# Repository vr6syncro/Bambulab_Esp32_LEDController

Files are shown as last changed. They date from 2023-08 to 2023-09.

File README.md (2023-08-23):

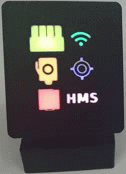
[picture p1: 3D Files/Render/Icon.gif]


# Bambulab Esp32 LEDController #

## Quick getting started - [for more details check this WIKI!](https://github.com/vr6syncro/Bambulab_Esp32_LEDController/wiki)

[Click here to get to the flasher.](https://vr6syncro.de/programmer/esp32.html "Click here to get to the flasher.")

The ESP32 is flashed with the firmware.

The ESP32 is now building a W-Lan access point with which we connect. The current password is: `password`

After that we have to navigate to the Wifimanager Config page with a browser.
The IP is: `192.168.4.1`

There you enter your W-Lan registration data.

Optionally, the Bambulab printer can be set up now or you can set it up later via the serial console or via the website.

If the EPS32 is connected to the WiFi, you should be able to find and reach it in your network.
The IP of the device is also output via the console if a programming app is installed.

As soon as you enter the IP of the EPS32 in your browser, you will get to the welcome page.
On the right side of the navigation you get to the configuration.

If the printer is not already connected, it reboots once after saving the data and it should connect to the MQTT.

[The 3D Files are at Printables, click here!](https://www.printables.com/de/model/501355-bambulab-esp32-ledcontroller)

## Hardware Infos
For a list of working ESP32 Controllers see [release](https://github.com/vr6syncro/Bambulab_Esp32_LEDController/releases).
    
    Pin 16 is connected with WS2812B Data Pin.

## OBS Stream Overlay
Just add your device ip/obs as webpage to OBS. If you want to change something you need to edit the obs file in src directory and self compile.

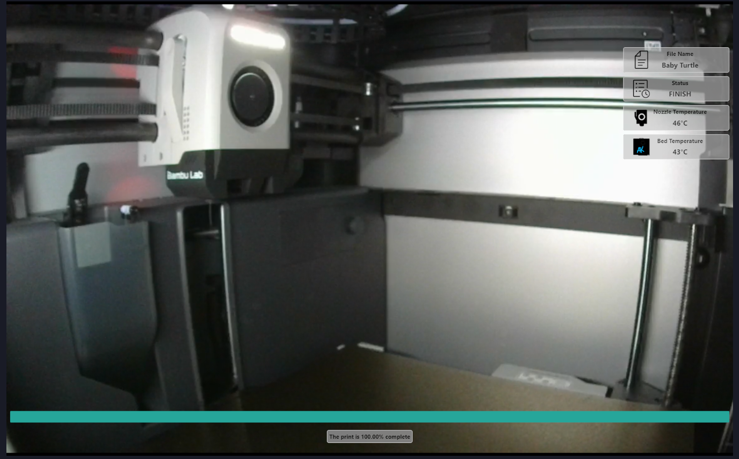
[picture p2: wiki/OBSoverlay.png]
overlay


### For more infos and help see my discord at: [http://discord.vr6syncro.de](http://discord.vr6syncro.de)

<a href="https://www.buymeacoffee.com/vr6syncro" target="_blank">Buy Me A Drink</a>

## License
This project is licensed under the "Attribution-NonCommercial-ShareAlike 4.0 International" License. See the [LICENSE](LICENSE) file for more details.

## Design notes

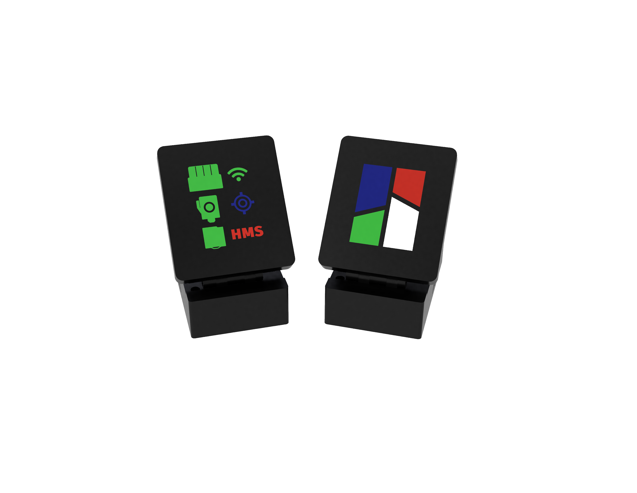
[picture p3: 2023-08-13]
3D Files/Render/Front.PNG

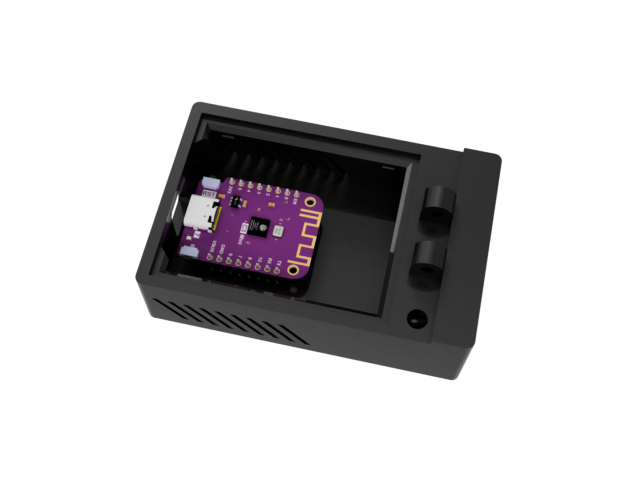
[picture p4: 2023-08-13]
3D Files/Render/Wemos C3.png

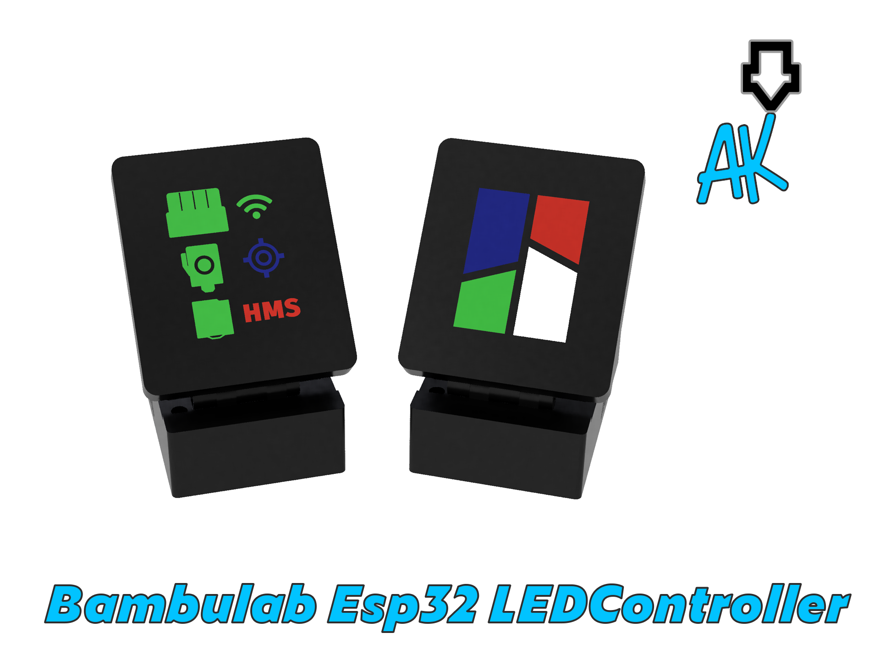
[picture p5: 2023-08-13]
3D Files/Render/Titelbild.png

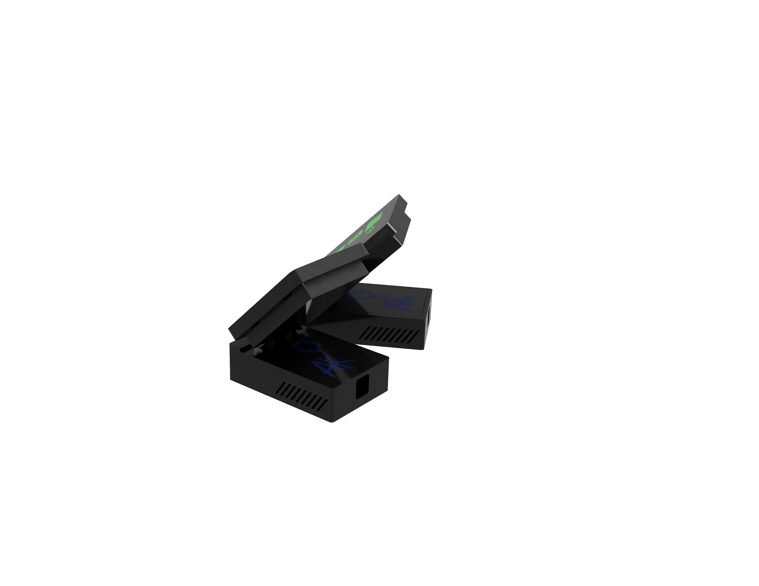
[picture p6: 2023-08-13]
3D Files/Render/Side.png

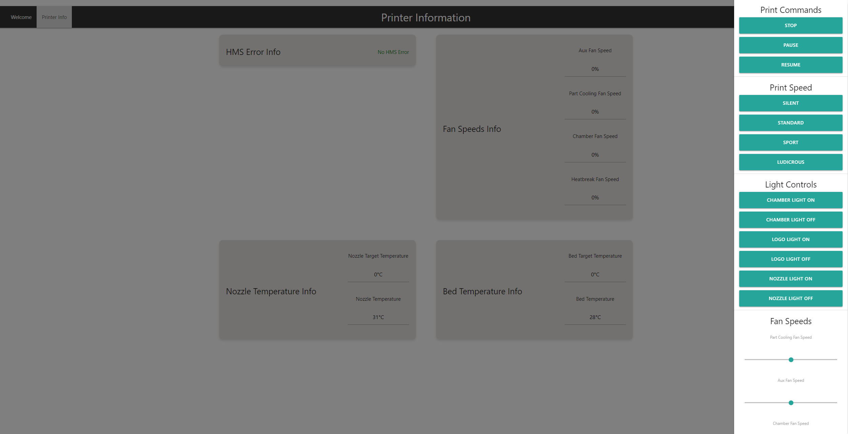
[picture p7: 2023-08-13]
wiki/CommandSidebar.png

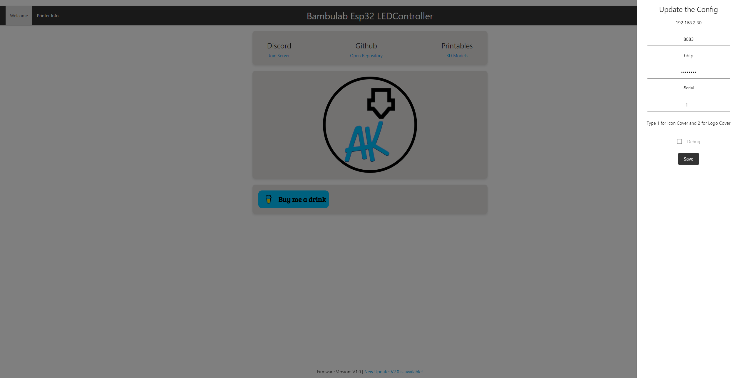
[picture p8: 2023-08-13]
wiki/ConfigSidebar.png

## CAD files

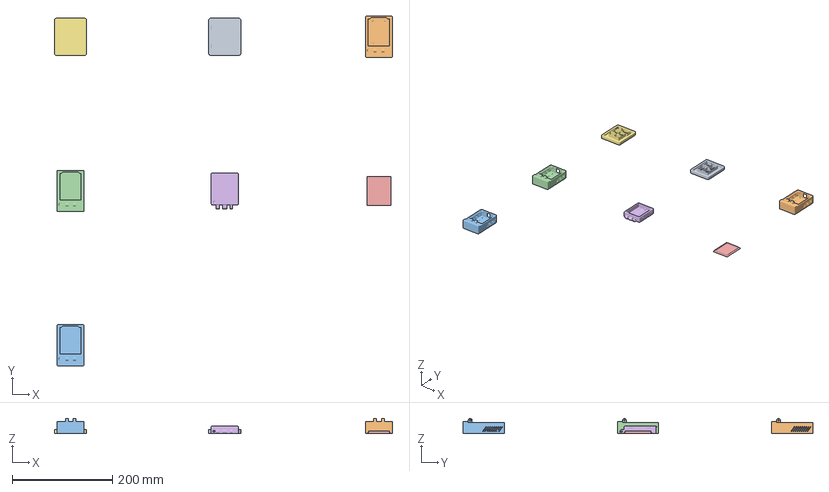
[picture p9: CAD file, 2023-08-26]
3D Files/Project File.3mf
673.4 x 696.7 x 30.0 mm
Frontcover Bambu Logo
Gehäuse_Dev Board and NodeMCU_V2
Gehäuse_Esp32_Wemos_d1_mini_V2
Gehäuse_ESP32_Wemos_C3_S2_V2
Deckel
Unterteil
Frontcover Icon

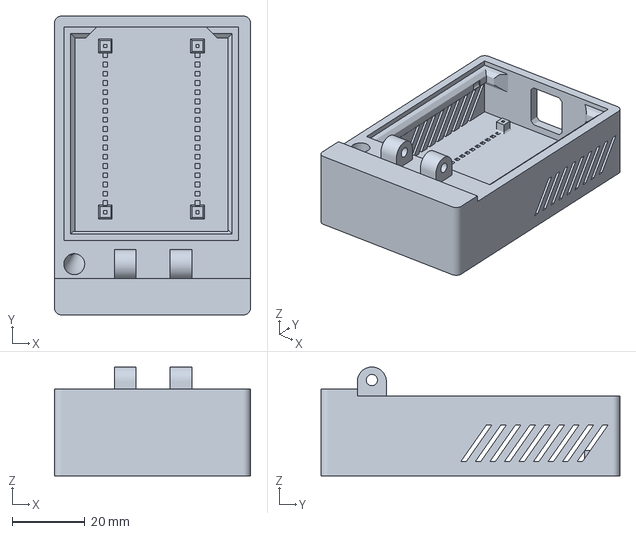
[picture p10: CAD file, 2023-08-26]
3D Files/Gehäuse_Dev Board and NodeMCU_V2.3mf
54.0 x 82.3 x 30.0 mm

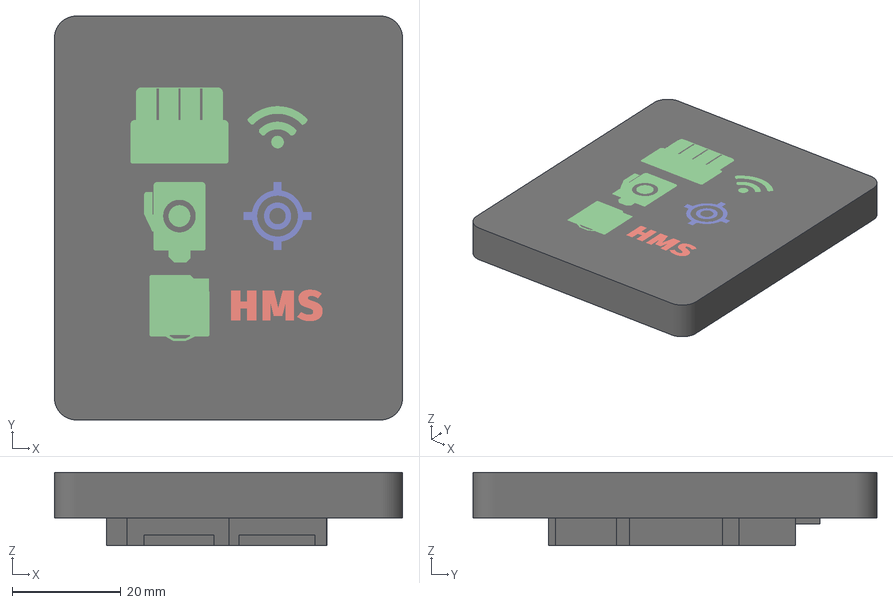
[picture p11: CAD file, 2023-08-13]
3D Files/Frontcover Icon.3mf
64.0 x 74.3 x 13.5 mm

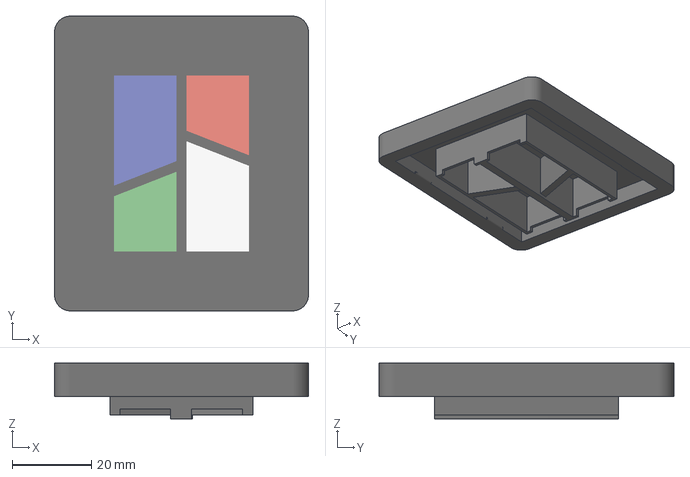
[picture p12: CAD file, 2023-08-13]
3D Files/Frontcover Bambu Logo.3mf
64.0 x 74.3 x 14.0 mm

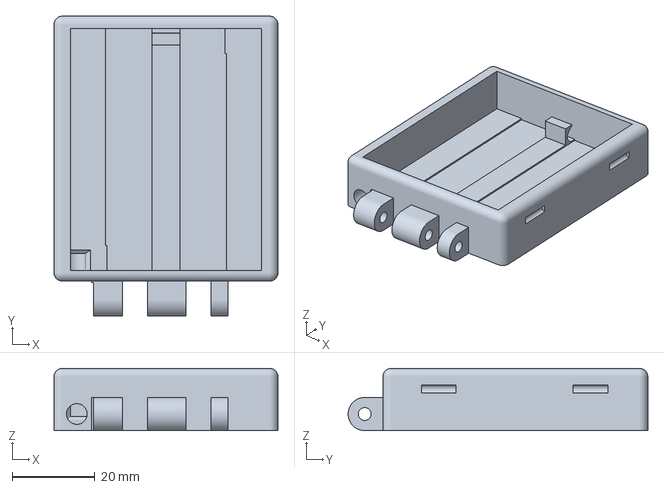
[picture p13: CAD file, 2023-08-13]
3D Files/Unterteil.3mf
54.0 x 72.3 x 15.0 mm

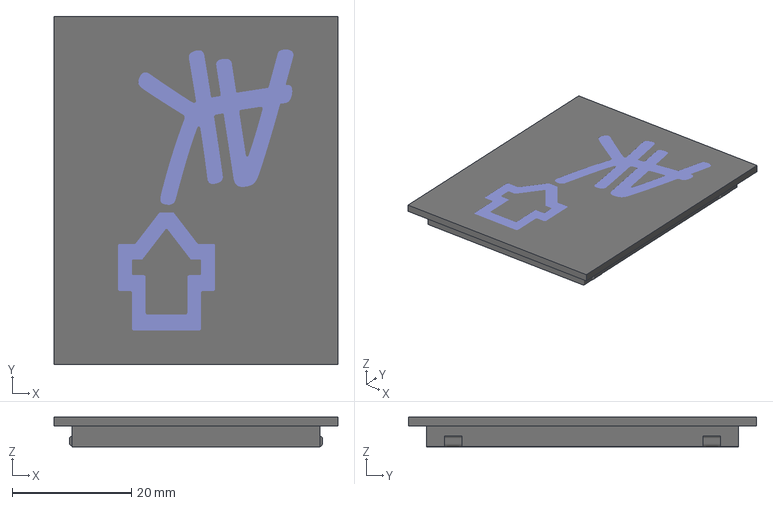
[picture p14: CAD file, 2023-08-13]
3D Files/Deckel.3mf
47.6 x 58.4 x 5.00 mm

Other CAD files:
3D Files/Gehäuse_Esp32_Wemos_d1_mini_V2.3mf
3D Files/Gehäuse_ESP32_Wemos_C3_S2_V2.3mf

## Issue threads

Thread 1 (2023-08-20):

NodeMCU V3.4 kompatibel?

PrintModz, 2023-08-20:
Ich versuche gerade die .bin Datei für das oben genannte Board aufzuspielen, jedoch ohne Erfolg. Der Flasher sagt andauernd, dass es sich um keine ESP Board handelt, obwohl es jedoch unter Arduino funktioniert.

Gibt es da vielleicht einen Trick?

Closed 2023-08-20.

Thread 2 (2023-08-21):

Your ESP8266 board is not supported.

PrintModz, 2023-08-21:
Hey,
die obige Meldung sagt alles, denn ich habe mir extra gestern 3 neue ESP8266 gekauft, welche jedoch nicht mit dem Flasher funktionieren. Erkannt werden diese zwar, jedoch ist ein Flashvorgang nicht möglich.

Wie kann ich sonst noch die Dateien auf den ESP bekommen?

Grüße

vr6syncro, 2023-08-21:
Hey, es wird nur der EP32 Supportet.

Closed 2023-08-21.

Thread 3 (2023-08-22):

Einige Fragen zum System

PrintModz, 2023-08-22:
Da ich nun den korrekten ESP habe und die Installation sowie Einrichtung funktioniert hat, stellen sich mir jedoch ein paar Fragen:

- Warum kann das Interface nicht aufgerufen werden, wenn die Installation funktioniert hat?
- Warum versucht er ständig mit dem MQTT zu verbinden?
- Was ist, wenn ich kein MQTT habe, ist das System dann unbrauchbar?
- Wo finde ich eine genaue Anleitung zum anschließen der PINS? Denn bei mir funktioniert es nicht und die Boards sind ja auch unterschiedlich?
- Warum soll die Seriennummer eingegeben werden? Ich habe es mal gemacht, werde mich da aber mit BambuLab in Verbindung setzen was das für Auswirkungen haben kann?
- Im Moment leider unbrauchbar, da es nicht funktioniert, wobei ich es mir schon gut vorstellen könnte, sollte es funktionieren.

viele Grüße

vr6syncro, 2023-08-23:
Hi, ich fange mal an das punkt für punkt abzuarbeiten:

-  Das Interface kann nicht aufgerufen werden wenn der ESP32 noch nicht vollständig intialisiert hat oder da was nicht passt.

-  Das ständige verbinden zeigt das dein MQTT Server (Das ist der 3D Drucker selber) nicht erreichbar ist und das der EPS32 die Verbindung aufbauen will.
- Solange du einen Bambulab Drucker hast hast du automatisch MQTT.
- Die ESP32 Boards sind von Hersteller zu Hersteller und von Revision zu Revision doch recht unterschiedlich. Man muss nun wissen was genau man für ein Board hat und googlet (Bildersuche) dann nach dem Boardnamen und zusätzlich den Begriff Pinout. Meistens kommt ziemlich vorne das passende. Oder man geht direkt zum Hersteller und nimmt das aus den technischen Daten. In der Software ist der PIN 16 für die LED Datenleitung hinterlegt. 5V und Masse sollten für jeden machbar sein denke ich.
-  Die Seriennummer benötigt der ESP32 für die MQTT Nachricht damit er auf die richtige Topic hört.
-  Nicht funktioniert ist zu allgemein gehalten um dir weiterhelfen zu können.

PrintModz, 2023-08-25:
Hey,
Danke für die Antworten, aber ich merke schon, dass das System für mich zu hoch ist.
Habe zwei identische ESP32 bei denen auch das Webinterface funktioniert, wobei es da reine Glückssache ist.
Denn auf dem einen ESP funktioniert es und auf dem anderen nicht. Auch funktionieren die LED´s nur einen ESP32 und nicht auf beide gleichzeitig, obwohl alle beiden die selbe Verkabelung haben.

Aber solange das Interface funktioniert und ich die Daten auf OBS anzeigen lassen kann, ist mir das recht. Interessant wäre noch, wenn man die OBS Infos noch selber anpassen könnte. ;)

Grüße

vr6syncro, 2023-08-25:
kannst du wenn du dir den code selber umschreibst ;)

hast du das szenario in den config richtig gesetzt?
normalerweise sollte das momentan super laufen.

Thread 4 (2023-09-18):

Update nicht möglich

PrintModz, 2023-09-18:
Es wird angezeigt, dass ein Update verfügbar ist. Beim auswählen und hochladen der Datei, bleibt das System weiterhin auf 2.1 stehen.
Bitte mal überprüfen!

vr6syncro, 2023-09-24:
Ist gefixed in der neuen Version

Closed 2023-09-24.

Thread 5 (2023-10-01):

Wiring plan esp 32 s2 mini

BoraSchninsky, 2023-10-01:
Hi can you upload a short handwritten wiring plan for the connection?

Can I use the esp32 s2 mini module?

I have it flashed with lolin and d1mini bin but nothing work's..

Thank you

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

Based on ESP32-S2FN4R2 WIFI IC
Type-C USB
4MB Flash
2MB PSRAM
27xIO
ADC, DAC, I2C, SPI, UART, USB OTG
Compatible with LOLIN D1 mini shields
Compatible with MicroPython, and ESP-IDF
Default firmware: MicroPython

BoraSchninsky, 2023-10-01:
I have tried to compile the source code in platformio but a error is in it.. can you compile it for the board?

Many thanks

vr6syncro, 2023-10-01:
Untested! It compiled in my software without issues. Here a image and files for flashing. But i dont know if OTA updates will work after it flashed sucessful.

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
[lolin_s2_mini.zip](https://github.com/vr6syncro/Bambulab_Esp32_LEDController/files/12776736/lolin_s2_mini.zip)

So if it is not working i cant test it because i dont have this board. Please use the supported one.

BoraSchninsky, 2023-10-01:
Mannnny thanks.. good guy

BoraSchninsky, 2023-10-01:
Now the board is running but whiteout mqtt..
And my second stripe on the right is not light up.

Thank you. I must show
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

vr6syncro, 2023-10-01:
slicer say heating bed... display show heating bed... connection and mqtt is ok... second strip maybe wrong soldered?

BoraSchninsky, 2023-10-14:
No .. soldering is ok ... I have it new soldered from ground up.. with new leds.

I don't know... 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

BoraSchninsky, 2023-10-14:
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

Now I looks good the stripe was in wrong direction.. jippi

vr6syncro, 2023-10-14:
DIN - DOUT wrong... common mistake ;)  Nice to hear that it's working now

Closed 2023-10-02.

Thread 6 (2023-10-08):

impossoble ti flash any esp

djepsylon, 2023-10-08:
hi,
i ve tried to flash your program on my esp32, on esp8266mod, on d1 mini with esp8266mod and impossible to flash anyone!
i ve also tried to download your source code and compile it in arduino ide but i don't find one library, i have alredy the error for the file update.h is missig but, i don't find the corect library who is associated with ths file.
Is this in link with ota and websocket correct? soo why i can't flash any esp? i ve tryed with anther program for see if this is not a problem with my drivers or my computer but i can put WLED in all my esp with their website flasher, it proof this is a problem with your code i think, no?
can you help me please?

best regards and good work! it is a qood add on for x1

vr6syncro, 2023-10-08:
First of all this project is ESP32 only. So no ESP8622 will work. Also if you download the source code you have to move all data in the scr folder to a folder what is named Bambulab_Esp32_LEDController for the Arduino IDE to work. The Update.h is a part of a libary that is missing as it seems. The Webflasher should work fine. Maybe your board is not supported or you have not installed the driver for it? It is hard to say because there are no more informations that you provide. I tested the Webflasher with a D1 Mini ESP32 and NODEMCU ESP32 and it worked fine. If you flash it with binarys yourself you have to use 4 files and set the offset to bootloader.bin 4096 - partitions.bin 32768 - boot_app0.bin 57344 - firmware.bin 65536. Maybe your board need a different offset but for my boards it was all the same.
[flash.zip](https://github.com/vr6syncro/Bambulab_Esp32_LEDController/files/12840221/flash.zip)

djepsylon, 2023-10-08:
hi, thanks a lot for you quickest answer
so if i understad well, my d1 mini with esp8266 is not compatble with the web flasher but i ve tested with a esp 32 wroom on a dev board and impossible to flash it too. well in arduino ide wat is the library associated to the update.h file? this is the only one missing. normally if i recompile for my esp8266 your program could work? correct?
for my es32 wroom i give you a photo of the hardware i use for you can see.
soo my knowlege about arduino ide is at the beggining state, can you help me for use your script with my esp8266 on my d1mini? i ave a lot of d1 esp8266 and i hve only one esp32wroom and i use it for another project
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

vr6syncro, 2023-10-08:
This ESP32 looks strange and i dont know this type of board.
The ESP8622 is not supported and will not work!

Have you any log message while flashing?

The update.h is part of the espressif esp32 libary.

please try: https://docs.espressif.com/projects/arduino-esp32/en/latest/installing.html

Closed 2023-10-15.

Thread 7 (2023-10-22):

LED Beleuchtung für Druckbett

Billiboy71, 2023-10-22:
Auf der Suche nach eine Druckerbeleuchtung bin ich über Euer Projekt gestolpert. Vielen Dank, das ist super.
könnte man das irgendwie abändern das man das wie in diesem Projekt macht. Mich stören dort die RGBWW LED Streifen, Neopixel sind viel cooler.
https://github.com/DutchDevelop/BambulabLedController

vr6syncro, 2023-10-23:
Update auf die V3 und teste den Strip Mode... https://github.com/vr6syncro/Bambulab_Esp32_LEDController/wiki/Strip-Mode

Falls du aber andere Farben haben willst musst du deine Firmware selber compilieren
https://github.com/vr6syncro/Bambulab_Esp32_LEDController/blob/main/src/ledhandle_stripe_case.h

Closed 2023-10-29.

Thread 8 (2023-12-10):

Feature request: Controller should display firmware variant, or link to exact firmware variant for ota update.

ZacFranken, 2023-12-10:
I received a notification that new firmware was available, the link took me to a page with several options.
I couldn’t remember which specific board I used for the unit. I couldn’t find on the web pages what exact binary variant that was loaded. So it took me a couple of goes to find the correct variant.

The firmware version is displayed at the bottom of the main page, it would be handy to see the exact firmware running in the device, (variant and version).

Another option is to link directly to the required file for that variant.

vr6syncro, 2023-12-11:
Hi, thanks for the suggestions.

It would certainly be possible to add something like that, but I don't think it's necessary at the moment.

The firmware should always work with a few exceptions.
I also think you could merge some firmware versions.

But I didn't test this and so I just offered all the common ones.

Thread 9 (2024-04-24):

Feature Request: Linking multiple ESP32s to create a pattern across multiple printers

bonninjd, 2024-04-24:
We have a print farm with 8 Bambu units on a rack.  It would be cool to have them syncing colors or chasing while printing.

vr6syncro, 2024-04-25:
Hello, this is possible, but requires deep code changes. You can fork the repository and modify it yourself. There will be no changes from my side until the bambulab api is released.

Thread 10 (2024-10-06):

connecting problems

djepsylon, 2024-10-06:
is your firmare fully functionnal with last firmwares of x1c?
my esp can't connect fully to all functions, i v only wifi and ams status working
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

vr6syncro, 2024-10-07:
Hi, I can't tell you at the moment. My printer is not on the latest firmware. But I haven't heard that they've changed anything there either. It "should" at least work.

Are the LEDs working as they should?

Do the problems only occur with the web interface?

What do the debug outputs say? Connect the controller to the serial console and activate the debug mode with "debug on"

Do the mqtt messages arrive?

You can try to see if the data is displayed on the obs website. To do this, enter /obs after the ip.

You can also check whether there are any errors in the browser.

Usually open with F12.

djepsylon, 2024-10-07:
hi, i ve found the problem, it was a firewall exception, i ve autorized the ip in my box and all works fine. sorry for loosing time. i think my operator have maked an update on the box who changed some firewall paramaters.

vr6syncro, 2024-10-08:
hi, no problem. nice to hear that it works now.

Closed 2024-10-08.

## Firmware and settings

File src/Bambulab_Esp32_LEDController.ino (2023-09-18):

#include "welcome.h"
#include "config.h"
#include <Preferences.h>
#include "ws2812b.h"
#include "ledhandle.h"
#include <WiFiClientSecure.h>
#include <PubSubClient.h>
#include <WiFiManager.h>
#include <ArduinoJson.h>
#include <ESPAsyncWebServer.h>
#include <AsyncTCP.h>
#include <WebSocketsServer.h>
#include <Update.h>
#include "ota.h"

// include the webpages
#include "startpage.h"
#include "infopage.h"
#include "obs.h"



// Function to get the printer stage description
const char* getPrinterStageDescription(int stage) {
  switch (stage) {
    case -1: return "Idle";
    case 0: return "Printing";
    case 1: return "Auto Bed Leveling";
    case 2: return "Heatbed Preheating";
    case 3: return "Sweeping XY Mech Mode";
    case 4: return "Changing Filament";
    case 5: return "M400 Pause";
    case 6: return "Paused due to filament runout";
    case 7: return "Heating Hotend";
    case 8: return "Calibrating Extrusion";
    case 9: return "Scanning Bed Surface";
    case 10: return "Inspecting First Layer";
    case 11: return "Identifying Build Plate Type";
    case 12: return "Calibrating Micro Lidar";
    case 13: return "Homing Toolhead";
    case 14: return "Cleaning Nozzle Tip";
    case 15: return "Checking Extruder Temperature";
    case 16: return "Printing was paused by the user";
    case 17: return "Pause of front cover falling";
    case 18: return "Calibrating Micro Lidar";
    case 19: return "Calibrating Extrusion Flow";
    case 20: return "Paused due to nozzle temperature malfunction";
    case 21: return "Paused due to heat bed temperature malfunction";
    default: return "Unknown stage";
  }
}

// Math code for HMS Error
String DecimalHexTwosComplement(int decimal) {
  char buffer[9];
  sprintf(buffer, "%08X", decimal);
  return String(buffer);
}

//for printer light led control
String createJsonLedControl(const char* led_node, const char* led_mode, int led_on_time, int led_off_time, int loop_times, int interval_time) {
  DynamicJsonDocument doc(1024);
  doc["system"]["sequence_id"] = sequence_id;
  doc["system"]["command"] = "ledctrl";
  doc["system"]["led_node"] = led_node;
  doc["system"]["led_mode"] = led_mode;
  doc["system"]["led_on_time"] = led_on_time;
  doc["system"]["led_off_time"] = led_off_time;
  doc["system"]["loop_times"] = loop_times;
  doc["system"]["interval_time"] = interval_time;

  String jsonString;
  serializeJson(doc, jsonString);
  return jsonString;
}

// für command
String createJsonCommand(const char* command, const char* param) {
  DynamicJsonDocument doc(1024);
  doc["print"]["sequence_id"] = String(sequence_id);
  doc["print"]["command"] = command;
  doc["print"]["param"] = param;

  String jsonString;
  serializeJson(doc, jsonString);
  return jsonString;
}

// für pushall
String createJsonMessage(const char* messageContent) {
  DynamicJsonDocument doc(1024);
  doc["message"] = messageContent;
  doc["sequence_id"] = sequence_id;

  String jsonString;
  serializeJson(doc, jsonString);
  return jsonString;
}

// MQTT-Server-Informationen
char mqtt_server[40];
char mqtt_port[6] = "8883";
char mqtt_user[30] = "bblp";
char mqtt_password[30];
char serial_number[20];
char mqtt_topic[200];

AsyncWebServer server(80);
WebSocketsServer ws(81);
WiFiClientSecure espClient;
PubSubClient client(espClient);

Preferences preferences;

void loadPreferences();
void savePreferences(WiFiManagerParameter& server, WiFiManagerParameter& port, WiFiManagerParameter& user, WiFiManagerParameter& password, WiFiManagerParameter& serial, WiFiManagerParameter& szenario_param);
void mqttCallback(char* topic, byte* payload, unsigned int length);
void configureSerial();
void sendPushAllCommand();
void ledControl();
void processHms(JsonArray hmsArray);
String askForInput(const String& prompt, const String& currentValue);
void publishMessage(const char* messageContent);
void sendPrintCommand(const char* command, const char* param);
void handleSerialCommands();
void publishPushAllMessage();
void sendGcodeCommand(const char* command, const char* param);
void sendLedControlCommand(const char* ledNode, const char* ledMode, int ledOnTime, int ledOffTime, int loopTimes, int intervalTime);

//save config from web
void saveConfigFromWeb(const String& server, const String& port, const String& user, const String& password, const String& serial, bool debugValue, int szenarioValue, int brightnessValue, int led_scenario_3Value) {
  preferences.begin("mqtt_config", false);
  preferences.putString("server", server.c_str());
  preferences.putString("port", port.c_str());
  preferences.putString("user", user.c_str());
  preferences.putString("password", password.c_str());
  preferences.putString("serial", serial.c_str());
  preferences.putBool("debug", debugValue);
  preferences.putString("brightness", String(brightnessValue).c_str());
  preferences.putString("szenario", String(szenarioValue).c_str());
  preferences.putString("led_scenario_3", String(led_scenario_3Value).c_str());
  preferences.end();
}

// wifimanager external config
void configModeCallback(WiFiManager* myWiFiManager) {
  Serial.println("Entered config mode");
  Serial.println(WiFi.softAPIP());

  Serial.println(myWiFiManager->getConfigPortalSSID());
}

// clear hms error
void clearHmsErrorInfo() {
  hms_error_count = 0;
  for (int i = 0; i < MAX_HMS_ERRORS; i++) {
    full_codes[i] = "";
    urls[i] = "";
  }
}

void setup() {
  Serial.begin(115200);
  client.setBufferSize(20000);

  // Preferences
  loadPreferences();

  initFastLED();
  setFastLedAllBlack();

  // WiFiManager
  WiFiManager wifiManager;
  setWifiConnecting();
  wifiManager.setClass("invert");
  wifiManager.setAPCallback(configModeCallback);

  // Custom parameters for configuration
  WiFiManagerParameter custom_mqtt_server("server", "Printer IP", mqtt_server, 40);
  WiFiManagerParameter custom_mqtt_port("port", "MQTT Port", mqtt_port, 6);
  WiFiManagerParameter custom_mqtt_user("user", "MQTT User", mqtt_user, 30);
  WiFiManagerParameter custom_mqtt_password("password", "Printer Accesscode", mqtt_password, 30);
  WiFiManagerParameter custom_serial_number("serial", "Printer Serial Number", serial_number, 20);
  WiFiManagerParameter custom_szenario("szenario", "Szenario (1=Icon, 2=Logo)", String(szenario).c_str(), 2);

  wifiManager.addParameter(&custom_mqtt_server);
  wifiManager.addParameter(&custom_mqtt_port);
  wifiManager.addParameter(&custom_mqtt_user);
  wifiManager.addParameter(&custom_mqtt_password);
  wifiManager.addParameter(&custom_serial_number);
  wifiManager.addParameter(&custom_szenario);

  wifiManager.setDebugOutput(true);

  if (wifiManager.autoConnect("Bambulab_Esp32_LEDController", "password")) {
    Serial.println("Connected to WiFi.");
    // Start the web server
    server.begin();
  } else {
    Serial.println("Failed to connect to WiFi.");
  }

  // Save updated parameters
  savePreferences(custom_mqtt_server, custom_mqtt_port, custom_mqtt_user, custom_mqtt_password, custom_serial_number, custom_szenario);

  // MQTT-Server-Konfiguration
  client.setServer(mqtt_server, atoi(mqtt_port));
  espClient.setInsecure();
  client.setCallback(mqttCallback);
  sprintf(mqtt_topic, "device/%s/report", serial_number);

  Serial.println("Initial setup complete.");
  Serial.println("Send 'config' to configure settings via serial console.");

  setupOTA();
  printWelcomeMessage();
  delay(3000);
  checkForUpdates();

  server.on("/", HTTP_GET, [](AsyncWebServerRequest* request) {
    String startpage_html_content = getStartPage();
    request->send(200, "text/html", startpage_html_content);
  });

  server.on("/info", HTTP_GET, [](AsyncWebServerRequest* request) {
    String infopage_html_content = getInfoPage();
    request->send(200, "text/html", infopage_html_content);
  });

  server.on("/obs", HTTP_GET, [](AsyncWebServerRequest* request) {
    String obspage_html_content = getOBSPage();
    request->send(200, "text/html", obspage_html_content);
  });

  server.on("/config", HTTP_GET, [](AsyncWebServerRequest* request) {
    // HTML-Formular für zusätzliche Konfigurationen senden
  });

  server.on("/control", HTTP_GET, [](AsyncWebServerRequest* request) {
    // Seite zur Steuerung senden
  });

  ws.begin();
  ws.onEvent([](uint8_t clientNum, WStype_t type, uint8_t* payload, size_t length) {
    switch (type) {
      case WStype_DISCONNECTED:
        if (debug) {
          Serial.printf("[%u] Disconnected!\n", clientNum);
        }
        break;
      case WStype_CONNECTED:
        {
          IPAddress ip = ws.remoteIP(clientNum);
          if (debug) {
            Serial.printf("[%u] Connected from %d.%d.%d.%d url: %s\n", clientNum, ip[0], ip[1], ip[2], ip[3], payload);
          }
        }
        break;
      case WStype_TEXT:
        if (debug) {
          Serial.printf("[%u] Received text: %s\n", clientNum, payload);
        }

        String receivedData = String((char*)payload);
        DynamicJsonDocument doc(1024);
        deserializeJson(doc, receivedData);

        if (doc["type"] == "mqttConfig") {
          String server = doc["server"].as<String>();
          String port = doc["port"].as<String>();
          String user = doc["user"].as<String>();
          String password = doc["password"].as<String>();
          String serial = doc["serial"].as<String>();
          bool debugValue = doc["debug"].as<bool>();
          int brightnessValue = doc["brightness"].as<int>();
          int szenarioValue = doc["szenario"].as<int>();
          int led_scenario_3Value = doc["led_scenario_3"].as<int>();

          saveConfigFromWeb(server, port, user, password, serial, debugValue, szenarioValue, brightnessValue, led_scenario_3Value);

          ws.sendTXT(clientNum, "Config saved successfully");

          delay(5000);
          ESP.restart();
        } else if (doc["type"] == "printCommand") {
          String command = doc["command"].as<String>();
          String value = doc["value"].as<String>();
          sendPrintCommand(command.c_str(), value.c_str());
        } else if (doc["type"] == "ledControl") {
          String light = doc["light"].as<String>();
          String state = doc["state"].as<String>();
          int arg1 = doc["arg1"].as<int>();
          int arg2 = doc["arg2"].as<int>();
          int arg3 = doc["arg3"].as<int>();
          int arg4 = doc["arg4"].as<int>();
          sendLedControlCommand(light.c_str(), state.c_str(), arg1, arg2, arg3, arg4);
        } else if (doc["type"] == "gcodeCommand") {
          String command = doc["command"].as<String>();
          String value = doc["value"].as<String>();
          sendGcodeCommand(command.c_str(), value.c_str());
        }
        break;
    }
  });
}

void loop() {
  // Prüfen, ob WiFi verbunden ist
  if (WiFi.status() == WL_CONNECTED) {
    if (!wifiConnected) {
      wifiConnected = true;
      pushAllCommandSent = false;
    }
  } else {
    wifiConnected = false;
  }

  // Prüfen, ob MQTT verbunden ist
  if (client.connected()) {
    if (!mqttConnected) {
      mqttConnected = true;
      sendPushAllCommand();
      pushAllCommandSent = true;
    }
  } else {
    mqttConnected = false;
  }

  // Wenn MQTT nicht verbunden ist, Verbindung versuchen herzustellen
  if (!client.connected() && (millis() - lastAttemptTime) > RECONNECT_INTERVAL) {
    if (client.connect("ESP32Client", mqtt_user, mqtt_password)) {
      Serial.println("Mit MQTT-Server verbunden");
      setMqttConnected();
      client.subscribe(mqtt_topic);
    } else {
      Serial.print("Fehler bei der Verbindung zum MQTT-Server: ");
      setMqttDisconnected();
      Serial.println(client.state());
      lastAttemptTime = millis();
    }
  }

  if (autoPushAllEnabled) {
    unsigned long currentMillis = millis();
    if (currentMillis - previousMillis >= 10000) {  // 10 seconds
      previousMillis = currentMillis;

      // Überprüfen, ob eine MQTT-Verbindung besteht, bevor publishPushAllMessage() aufgerufen wird
      if (client.connected()) {
        if (debug) {
          Serial.println("Requesting pushAll...");
        }
        publishPushAllMessage();
      }
    }
  }

  if (hmsErrorExists != previousHmsErrorExists) {
    if (!hmsErrorExists) {
      clearHmsErrorInfo();
    }
    previousHmsErrorExists = hmsErrorExists;
  }

  ledControlSwitch();
  client.loop();
  handleSerialCommands();
  ws.loop();
}

//send pushall mqtt message
void publishPushAllMessage() {
  if (client.connected()) {
    char publish_topic[128];
    sprintf(publish_topic, "device/%s/request", serial_number);

    DynamicJsonDocument doc(1024);
    doc["pushing"]["sequence_id"] = sequence_id;
    doc["pushing"]["command"] = "pushall";

    String jsonMessage;
    serializeJson(doc, jsonMessage);

    // Log the JSON message if debugging is enabled
    if (debug) {
      Serial.println("JSON message to send: " + jsonMessage);
    }

    bool success = client.publish(publish_topic, jsonMessage.c_str());

    if (success) {
      if (debug) {
        Serial.print("Nachricht erfolgreich gesendet an: ");
        Serial.println(publish_topic);
      }
    } else {
      Serial.println("Fehler beim Senden der Nachricht.");
    }

    // Log the result of client.publish() if debugging is enabled
    if (debug) {
      Serial.println("client.publish() returned: " + String(success));
    }

    // Erhöhe die sequence_id um 1
    sequence_id++;
  } else {
    Serial.println("Nicht mit MQTT-Broker verbunden!");
  }
}

//send mqtt message
void publishMessage(const char* messageContent) {
  if (client.connected()) {
    char publish_topic[128];
    sprintf(publish_topic, "device/%s/request", serial_number);

    String jsonMessage = createJsonMessage(messageContent);

    // Log the JSON message if debugging is enabled
    if (debug) {
      Serial.println("JSON message to send: " + jsonMessage);
    }

    bool success = client.publish(publish_topic, jsonMessage.c_str());

    if (success) {
      Serial.print("Nachricht erfolgreich gesendet an: ");
      Serial.println(publish_topic);
    } else {
      Serial.println("Fehler beim Senden der Nachricht.");
    }

    // Log the result of client.publish() if debugging is enabled
    if (debug) {
      Serial.println("client.publish() returned: " + String(success));
    }

    // Erhöhe die sequence_id um 1
    sequence_id++;
  } else {
    Serial.println("Nicht mit MQTT-Broker verbunden!");
  }
}

//load config
void loadPreferences() {
  preferences.begin("mqtt_config", false);
  preferences.getString("server", mqtt_server, sizeof(mqtt_server));
  preferences.getString("port", mqtt_port, sizeof(mqtt_port));
  preferences.getString("user", mqtt_user, sizeof(mqtt_user));
  preferences.getString("password", mqtt_password, sizeof(mqtt_password));
  preferences.getString("serial", serial_number, sizeof(serial_number));
  debug = preferences.getBool("debug");
  String szenario_string = preferences.getString("szenario", "1");
  szenario = szenario_string.toInt();
  String brightness_string = preferences.getString("brightness", "24");
  brightness = brightness_string.toInt();
  String led_scenario_3_string = preferences.getString("led_scenario_3" , "1");
  led_scenario_3 = led_scenario_3_string.toInt();
  preferences.end();
}

//save config
void savePreferences(WiFiManagerParameter& server, WiFiManagerParameter& port, WiFiManagerParameter& user, WiFiManagerParameter& password, WiFiManagerParameter& serial, WiFiManagerParameter& szenario_param) {
  preferences.begin("mqtt_config", false);
  preferences.putString("server", server.getValue());
  preferences.putString("port", port.getValue());
  preferences.putString("user", user.getValue());
  preferences.putString("password", password.getValue());
  preferences.putString("serial", serial.getValue());
  preferences.putBool("debug", debug);
  preferences.putString("szenario", szenario_param.getValue());
  preferences.end();
}

// mqtt json parser
void mqttCallback(char* topic, byte* payload, unsigned int length) {
  if (length == 2 && payload[0] == '{' && payload[1] == '}') {
    if (debug) {
      Serial.println("Leere Nachricht empfangen");
    }
    return;
  }

  DynamicJsonDocument doc(20000);
  DeserializationError error = deserializeJson(doc, payload, length);

  if (error) {
    Serial.print(F("deserializeJson() failed: "));
    Serial.println(error.c_str());
    return;
  }

  if (doc.containsKey("print") && doc["print"].containsKey("stg_cur")) {
    printer_stage = doc["print"]["stg_cur"].as<int>();
  }
  if (doc.containsKey("print") && doc["print"].containsKey("print_real_action")) {
    printer_real_stage = doc["print"]["print_real_action"];
  }
  unsigned int received_sequence_id = doc["print"]["sequence_id"].as<unsigned int>();

  if (doc.containsKey("print")) {
    JsonObject printObject = doc["print"];

    if (printObject.containsKey("gcode_state")) {
      gcodeState = printObject["gcode_state"].as<String>();
      if (debug) {
        Serial.println("Gcode State: " + gcodeState);
      }
    }

    if (printObject.containsKey("hms")) {
      JsonArray hmsArray = printObject["hms"];
      if (hmsArray.size() == 0) {
        // HMS-Fehler wurde aufgehoben
        if (debug) {
          Serial.println("Kein HMS-Fehler vorhanden.");
        }
        hmsErrorExists = false;
      } else {
        // HMS-Fehler vorhanden
        processHms(hmsArray);
        hmsErrorExists = true;
      }
    }

    // Abgreifen der neuen Felder (falls vorhanden)
    if (printObject.containsKey("big_fan1_speed")) {
      bigFan1Speed = printObject["big_fan1_speed"].as<int>();
    }

    if (printObject.containsKey("cooling_fan_speed")) {
      coolingFanSpeed = printObject["cooling_fan_speed"].as<int>();
    }

    // Weitere Felder, die abgegriffen werden können
    if (printObject.containsKey("big_fan2_speed")) {
      bigFan2Speed = printObject["big_fan2_speed"].as<int>();
    }

    if (printObject.containsKey("chamber_temper")) {
      chamberTemperature = printObject["chamber_temper"].as<int>();
    }

    if (printObject.containsKey("heatbreak_fan_speed")) {
      heatbreakFanSpeed = printObject["heatbreak_fan_speed"].as<int>();
    }

    if (printObject.containsKey("nozzle_target_temper")) {
      nozzleTargetTemperature = printObject["nozzle_target_temper"].as<int>();
    }

    if (printObject.containsKey("nozzle_temper")) {
      nozzleTemperature = printObject["nozzle_temper"].as<int>();
    }

    if (printObject.containsKey("bed_target_temper")) {
      bedTargetTemperature = printObject["bed_target_temper"].as<int>();
    }

    if (printObject.containsKey("bed_temper")) {
      bedTemperature = printObject["bed_temper"].as<int>();
    }

    if (printObject.containsKey("aux_part_fan")) {
        aux_part_fan = printObject["aux_part_fan"].as<bool>();
    }

    if (printObject.containsKey("gcode_file")) {
        gcode_file = printObject["gcode_file"].as<String>();
    }

    if (printObject.containsKey("total_layer_num")) {
        total_layer_num = printObject["total_layer_num"].as<int>();
    }

    if (printObject.containsKey("layer_num")) {
        layer_num = printObject["layer_num"].as<int>();
    }


    if (printObject.containsKey("subtask_name")) {
        subtask_name = printObject["subtask_name"].as<String>();
    }
  }

  if (received_sequence_id > sequence_id) {
    sequence_id = received_sequence_id;
  }
  if (debug) {
    Serial.print("Nachricht empfangen");
  }

  Serial.println(".");
  if (debug) {
    Serial.print(" [");
    Serial.print(topic);
    Serial.print("]");
    Serial.println();
    serializeJsonPretty(doc, Serial);
    Serial.println();
    Serial.print("Empfangene Payload-Länge: ");
    Serial.println(length);
  }
  // Websocket
  DynamicJsonDocument webData(20000);

  webData["printer_stage"] = printer_stage;
  webData["printer_real_stage"] = printer_real_stage;
  webData["gcodeState"] = gcodeState;
  webData["hmsErrorExists"] = hmsErrorExists;
  webData["bigFan1Speed"] = bigFan1Speed;
  webData["coolingFanSpeed"] = coolingFanSpeed;
  webData["bigFan2Speed"] = bigFan2Speed;
  webData["chamberTemperature"] = chamberTemperature;
  webData["heatbreakFanSpeed"] = heatbreakFanSpeed;
  webData["nozzleTargetTemperature"] = nozzleTargetTemperature;
  webData["nozzleTemperature"] = nozzleTemperature;
  webData["bedTargetTemperature"] = bedTargetTemperature;
  webData["bedTemperature"] = bedTemperature;
  webData["aux_part_fan"] = aux_part_fan;
  webData["gcode_file"] = gcode_file;
  webData["total_layer_num"] = total_layer_num;
  webData["subtask_name"] = subtask_name;
  webData["layer_num"] = layer_num;
  webData["gcodeState"] = gcodeState;


  JsonArray fullCodesArray = webData.createNestedArray("full_codes");
  JsonArray urlsArray = webData.createNestedArray("urls");

  for (int i = 0; i < hms_error_count; i++) {
    fullCodesArray.add(full_codes[i]);
    urlsArray.add(urls[i]);
  }


  // Konvertieren Sie das JSON-Dokument in einen String
  String webMessage;
  serializeJson(webData, webMessage);

  // Senden Sie die Daten an alle verbundenen WebSocket-Clients
  ws.broadcastTXT(webMessage);
}

// debug for hms error
void debugHmsErrorStatus() {
  Serial.print("hmsErrorExists: ");
  Serial.println(hmsErrorExists ? "true" : "false");
}
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

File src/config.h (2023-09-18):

#ifndef CONFIG_H
#define CONFIG_H

const char* firmwareVersion = "V3.0";

int szenario = 1;
bool updateAvailable = false;
bool updateChecked = false;
String latestVersion = "";
bool debug = true;
bool hmsErrorExists = false;
bool hmsErrorPresent = false;
bool previousHmsErrorExists = false;
bool autoPushAllEnabled = true;
bool pushAllCommandSent = false;
bool wifiConnected = false;
bool mqttConnected = false;
int printer_stage = -2;
int printer_real_stage = -2;
bool f_layerInspection = false;
int bigFan1Speed = 0;
int coolingFanSpeed = 0;
int bigFan2Speed = 0;
int chamberTemperature = 0;
int heatbreakFanSpeed = 0;
int nozzleTargetTemperature = 0;
int nozzleTemperature = 0;
int bedTargetTemperature = 0;
int bedTemperature = 0;
bool aux_part_fan = false;
String gcode_file = "";
int total_layer_num = 0;
int layer_num = 0;
String subtask_name = "";
String gcodeState;
unsigned int sequence_id = 0;
unsigned long previousMillis = 0;

#define MAX_HMS_ERRORS 10  // Maximum number of HMS errors that can be tracked at once

String full_codes[MAX_HMS_ERRORS];  // Array to store the full HMS codes
String urls[MAX_HMS_ERRORS];        // Array to store the URLs
int hms_error_count = 0;            // Variable to keep track of the number of HMS errors

// mqtt not connected
unsigned long lastAttemptTime = 0;
const unsigned long RECONNECT_INTERVAL = 5000;  // 5 seconds

// Print finished
unsigned long finishTime = 0;
const unsigned long finishDisplayDuration = 180000; //3 minutes
bool finishProcessed = false;

#endif

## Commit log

2023-08-11 v5
    ixed a bug that cause szenario switch not working
    implemented a blink, fadein/out and rainbow effect - finally some led effects are back 😎
    some console output
2023-08-13 Added 3D Files
    initial release of the 3D Printed Files
    [Deckel.3mf, Frontcover Bambu Logo.3mf, Frontcover Icon.3mf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]
2023-08-13 OTA improvments
    added handler to switch the website after flashing over ota is finished
2023-08-13 OTA and 3D File fix
    [Gehäuse_ESP32_Wemos Universal.3mf, Gehäuse_NodeMcu.3mf]
2023-08-13 Updated Project
    [Project File.3mf]
2023-08-13 more boards and more magnets
    [Gehäuse_Dev Board and NodeMCU.3mf, Gehäuse_ESP32_Wemos Universal.3mf, Gehäuse_Esp32_Wemos_d1_mini.3mf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]
2023-08-13 rename and update project
    [Gehäuse_ESP32_Wemos_C3_S2.3mf, Project File.3mf]
2023-08-17 fixed brightness console command
    [Bambulab_Esp32_LEDController.ino]
2023-08-17 removed some boards
2023-08-19 update led control and try firstlayer fix
    [config.h, effects.h]
2023-08-19 new Printer info website image
2023-08-26 moved print name to progressbar
2023-08-26 fix pin diameter
    [Gehäuse_Dev Board and NodeMCU.3mf, Gehäuse_Dev Board and NodeMCU_V2.3mf, Gehäuse_ESP32_Wemos_C3_S2.3mf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]
2023-08-26 updated project file with v2 parts
    [Project File.3mf]
2023-09-18 added Strip Mode fixed Version added set Brightness to Web Config Page
    [Bambulab_Esp32_LEDController.ino, config.h, effects.h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]
